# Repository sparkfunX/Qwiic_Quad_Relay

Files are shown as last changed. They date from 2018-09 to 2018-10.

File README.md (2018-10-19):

SparkX Qwiic Quad Relay
========================================

-> SparkX Qwiic Quad Relay (https://cdn.sparkfun.com/assets/parts/1/3/3/6/3/15032-Qwiic_Quad_Relay-01.jpg) <-

[*SparkX Qwiic Quad Relay (SPX-15032)*](https://www.sparkfun.com/products/15032)
The Qwiic Quad Relay is a product designed for switching not one, but **four** high powered devices, from your Arduino or other low powered microcontroller using I<sup>2</sup>C. It's rocking four [relays](https://www.sparkfun.com/products/100) on its' PCB rated up to 5 Amps per channel at 250VAC. Each channel is sporting its own colored LED and silk for easy identification, and has screw terminals for easy connection. 

The board is made to integrate easily into the [Qwiic environment](https://www.sparkfun.com/qwiic) with Qwiic connectors on each side for easy daisy chaining. At the heart of the product is an ATtiny84 with its own I<sup>2</sup>C address awaiting for I<sup>2</sup>C commands that are designated to turn on and off individual channels or _all_ the channels at once! All of this is detailed nicely in provided example code, which also walks you through changing the boards single I<sup>2</sup>C address. There is a four pin header broken out for those of you not taking advantage of the Qwiic connector.

The onboard barrel jack is rated for wall warts in the range, 7-15V but there is a jumper on the underside in the case that your wall wart is 5V. Messing with such high voltage can be dangerous! We've included many safety precautions onto the PCB including, wide traces designed for high amperage, ground isolation between the relay and other circuitry, and a milled out area around the common pin of the relay.

Repository Contents
-------------------

* **/Firmware** - Latest firmware and examples. 
* **/Arduino Example** - Examples on how to use the product with buttons and switches, with hardware interrupts and without.
* **/Hardware** - Eagle design files (.brd, .sch)

License Information
-------------------

This product is _**open source**_! 

Please review the LICENSE.md file for license information. 

If you have any questions or concerns on licensing, please contact techsupport@sparkfun.com.

Please use, reuse, and modify these files as you see fit. Please maintain attribution to SparkFun Electronics and release under the same license.

Distributed as-is; no warranty is given.

- Your friends at SparkFun.

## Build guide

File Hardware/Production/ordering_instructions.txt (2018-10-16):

panel size, 180x118mm
PCB thickness, 1.6mm
number of layers, 2
soldermask color, Black
silkscreen color, White
oz copper, 1oz
finish, HASL lead free
stencils, top+bottom
pcs per panel, 4

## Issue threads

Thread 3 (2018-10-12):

Change resistor values to 1k on LEDs

edspark, 2018-10-12:

edspark, 2018-10-16:
Fixed, see commit:
0d556fc5444e4cb48f6ed6b3425d6cf99cb9de57

Closed 2018-10-16.

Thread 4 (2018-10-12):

Update Relay Package

edspark, 2018-10-12:

edspark, 2018-10-16:
Fixed, see commit:
0d556fc5444e4cb48f6ed6b3425d6cf99cb9de57

Closed 2018-10-16.

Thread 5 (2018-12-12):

Set on/off  not just toggle?

HeneryH, 2018-12-12:
I only see commands in the sample code to toggle individual relays.

I need to set a relay to ON.  Not just toggle it.

What is the command for setting relay x to ON or OFF?

edspark, 2018-12-12:
Hello Henry!

Currently there is only the option to toggle the individual relays. I've been trying to imagine what situation a hard **on** command would be better than going from on->off->on etc. Do you mind sharing why you might need to do that?

As a possible solution to your problem, you could use the command to get the status of the relay before you decide to turn it on or off. For example: "check if relay is on" --> if **off**, toggle relay otherwise leave it **on**.

HeneryH, 2018-12-12:
I have a pi based home controller that communicates with a variety of arduino based wireless nodes.

I just created a node type for the Quad Relay Controller that allows me to set and check any of the relays.

On that controller are buttons to turn any relays on or off.   The functions I am writing take a relay index and a command (on/off).

I suppose that I just need to track its current state and if the requested state isn't the same as the current state then toggle.

Closed 2018-12-12.

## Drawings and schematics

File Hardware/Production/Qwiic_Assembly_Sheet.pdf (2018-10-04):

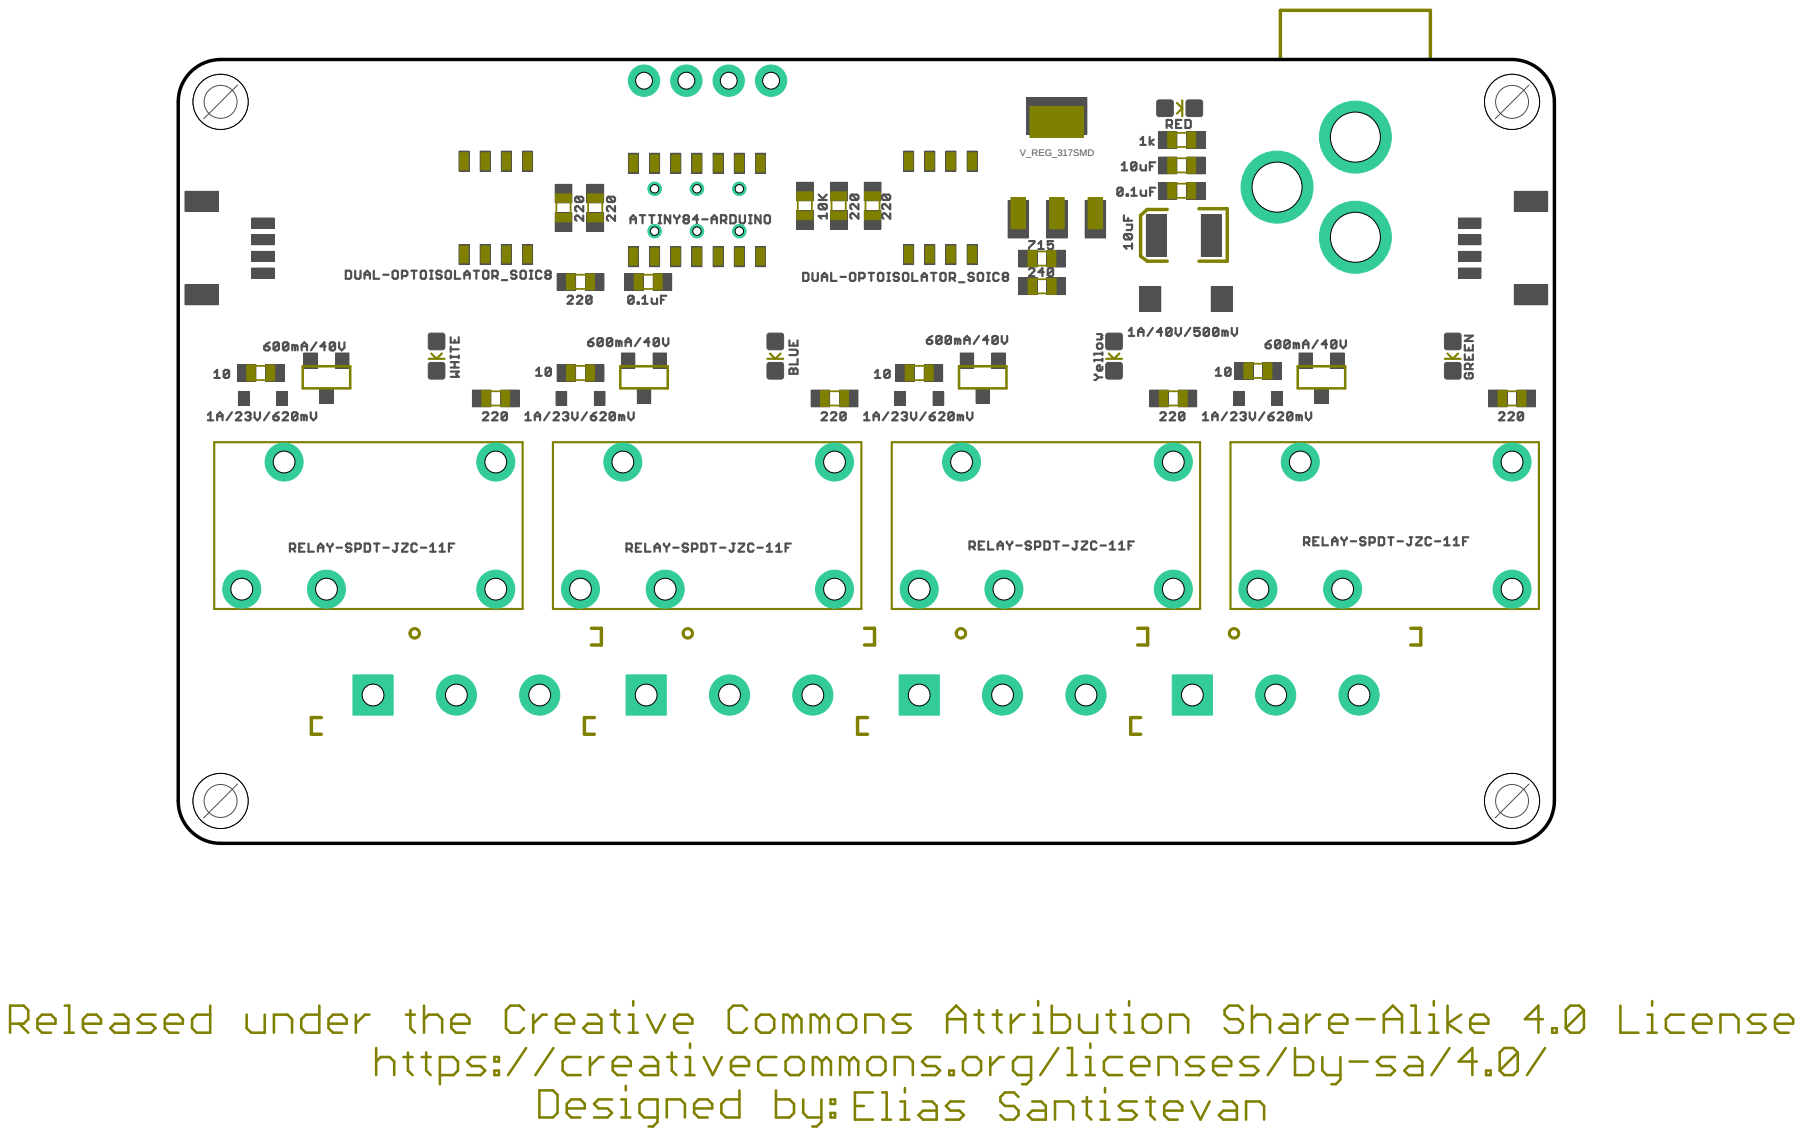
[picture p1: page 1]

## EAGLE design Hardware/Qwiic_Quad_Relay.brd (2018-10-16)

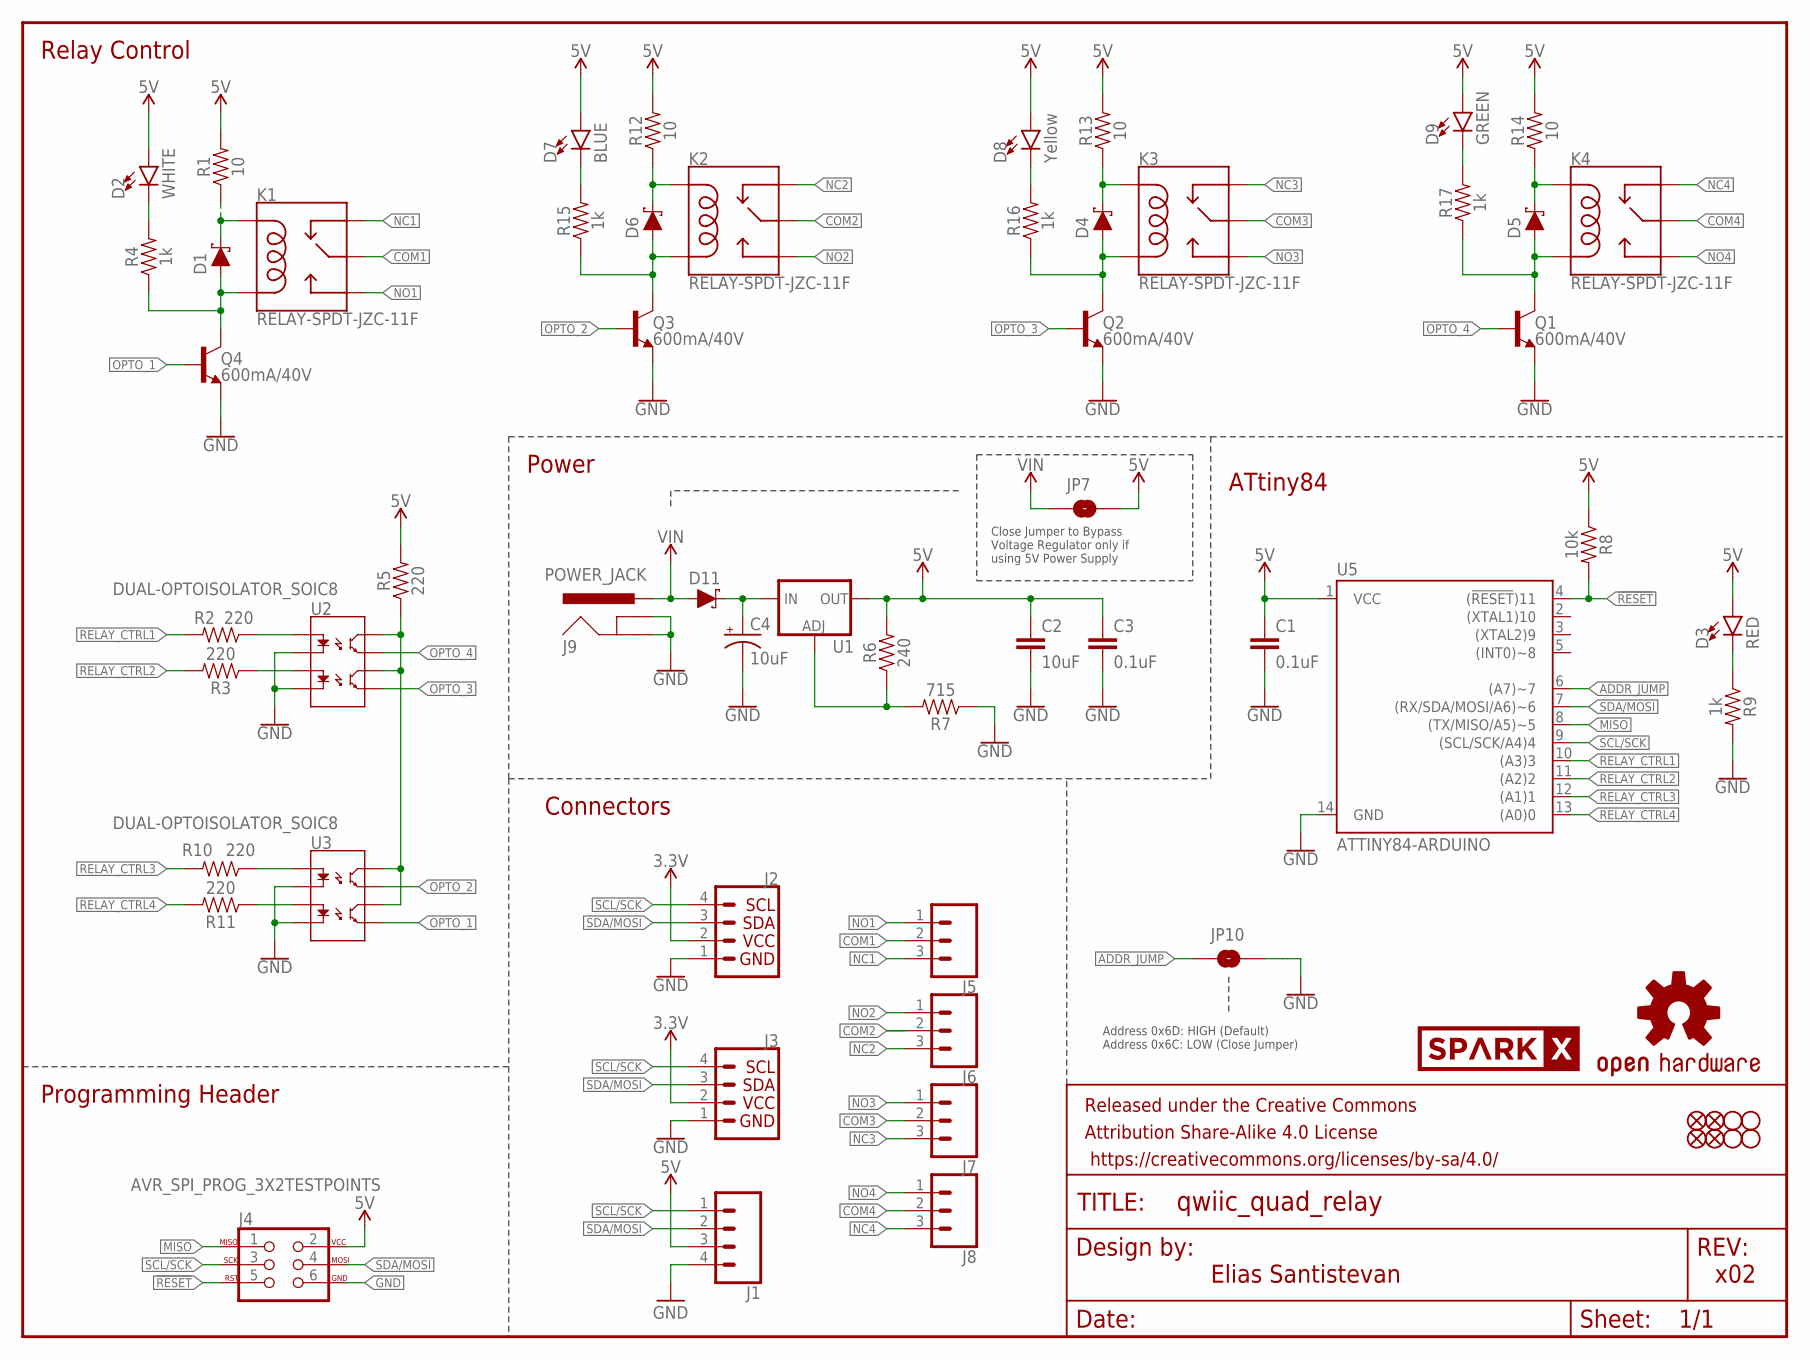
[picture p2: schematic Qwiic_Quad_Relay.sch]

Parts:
C1, C3: 0.1uF; 0603
C2: 10uF; 0603
C4: 10uF; EIA3528
D1, D4, D5, D6: 1A/23V/620mV; SOD-323
D2: WHITE; LED-0603
D3: RED; LED-0603
D7: BLUE; LED-0603
D8: Yellow; LED-0603
D9: GREEN; LED-0603
D11: 1A/40V/500mV; SMA-DIODE
FRAME1: FRAME-LETTER; CREATIVE_COMMONS
J1: CONN_041X04_NO_SILK; 1X04_NO_SILK
J2, J3: Qwiic Right Angle; 1X04_1MM_RA
J4: AVR_SPI_PROG_3X2TESTPOINTS; 2X3_TEST_POINTS
J5, J6, J7, J8: CONN_03-SCREW-5MM; SCREWTERMINAL-5MM-3
J9: POWER_JACK; POWER_JACK_PTH
JP1, JP3, JP4, JP5: STAND-OFF
JP2, JP6, JP8, JP9: FIDUCIAL1X2; FIDUCIAL-1X2
JP7, JP10: JUMPER-SMT_2_NO_SILK; SMT-JUMPER_2_NO_SILK
K1, K2, K3, K4: RELAY-SPDT-JZC-11F; RELAY-JZC
LOGO1: OSHW-LOGOS; OSHW-LOGO-S
Q1, Q2, Q3, Q4: 600mA/40V; SOT23-3
R1, R12, R13, R14: 10; 0603
R2, R3, R5, R10, R11: 220; 0603
R4, R9, R15, R16, R17: 1k; 0603
R6: 240; 0603
R7: 715; 0603
R8: 10k; 0603
U1: V_REG_LM1117SOT223; SOT223
U2, U3: DUAL-OPTOISOLATOR_SOIC8; SO08
U5: ATTINY84-ARDUINO; SO14
U$12: SPARKX-LOGO4; SPARKX-MEDIUM

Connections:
3.3V: J2.2, J3.2
5V: C1.1, C2.1, C3.1, D2.A, D3.A, D7.A, D8.A, D9.A, J1.3, J4.2, JP7.2, R1.2, R5.2, R6.2, R8.1, R12.2, R13.2, R14.2, U1.2 (OUT), U1.4 (OUT), U5.1 (VCC)
!RESET: J4.5, R8.2, U5.4 ((!RESET!)11)
ADDR_JUMP: JP10.1, U5.6 ((A7)~7)
COM1: J5.2, K1.4 (MAIN)
COM2: J6.2, K2.4 (MAIN)
COM3: J7.2, K3.4 (MAIN)
COM4: J8.2, K4.4 (MAIN)
GND: C1.2, C2.2, C3.2, C4.C (-), J1.4, J2.1, J3.1, J4.6, J9.GND, J9.GNDBREAK, JP10.2, Q1.2 (E), Q2.2 (E), Q3.2 (E), Q4.2 (E), R7.1, R9.2, U2.2 (C1), U2.4 (C2), U3.2 (C1), U3.4 (C2), U5.14 (GND)
MISO: J4.1, U5.8 ((TX/MISO/A5)~5)
unnamed: D6.C, K2.5 (COIL1), R12.1
unnamed: D1.A, K1.1 (COIL2), Q4.3 (C), R4.1
unnamed: R11.1, U3.3 (A2)
unnamed: C4.A (+), D11.C, U1.3 (IN)
unnamed: R10.1, U3.1 (A1)
unnamed: R5.1, U2.6 (CL2), U2.8 (CL1), U3.6 (CL2), U3.8 (CL1)
unnamed: D1.C, K1.5 (COIL1), R1.1
unnamed: D2.C, R4.2
unnamed: R2.1, U2.1 (A1)
unnamed: R3.1, U2.3 (A2)
unnamed: D6.A, K2.1 (COIL2), Q3.3 (C), R15.1
unnamed: D3.C, R9.1
unnamed: D4.C, K3.5 (COIL1), R13.1
unnamed: D4.A, K3.1 (COIL2), Q2.3 (C), R16.1
unnamed: D5.C, K4.5 (COIL1), R14.1
unnamed: D5.A, K4.1 (COIL2), Q1.3 (C), R17.1
unnamed: R6.1, R7.2, U1.1 (ADJ)
unnamed: D9.C, R17.2
unnamed: D8.C, R16.2
unnamed: D7.C, R15.2
NC1: J5.3, K1.2 (NC)
NC2: J6.3, K2.2 (NC)
NC3: J7.3, K3.2 (NC)
NC4: J8.3, K4.2 (NC)
NO1: J5.1, K1.3 (NO)
NO2: J6.1, K2.3 (NO)
NO3: J7.1, K3.3 (NO)
NO4: J8.1, K4.3 (NO)
OPTO_1: Q4.1 (B), U3.5 (EM2)
OPTO_2: Q3.1 (B), U3.7 (EM1)
OPTO_3: Q2.1 (B), U2.5 (EM2)
OPTO_4: Q1.1 (B), U2.7 (EM1)
RELAY_CTRL1: R2.2, U5.10 ((A3)3)
RELAY_CTRL2: R3.2, U5.11 ((A2)2)
RELAY_CTRL3: R10.2, U5.12 ((A1)1)
RELAY_CTRL4: R11.2, U5.13 ((A0)0)
SCL/SCK: J1.1, J2.4, J3.4, J4.3, U5.9 ((SCL/SCK/A4)4)
SDA/MOSI: J1.2, J2.3, J3.3, J4.4, U5.7 ((RX/SDA/MOSI/A6)~6)
VIN: D11.A, J9.PWR, JP7.1

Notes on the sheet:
Elias Santistevan
x02
Relay Control
Connectors
ATtiny84
Programming Header
Power
Close Jumper to Bypass Voltage Regulator only if using 5V Power Supply
Address 0x6D: HIGH (Default) Address 0x6C: LOW (Close Jumper)

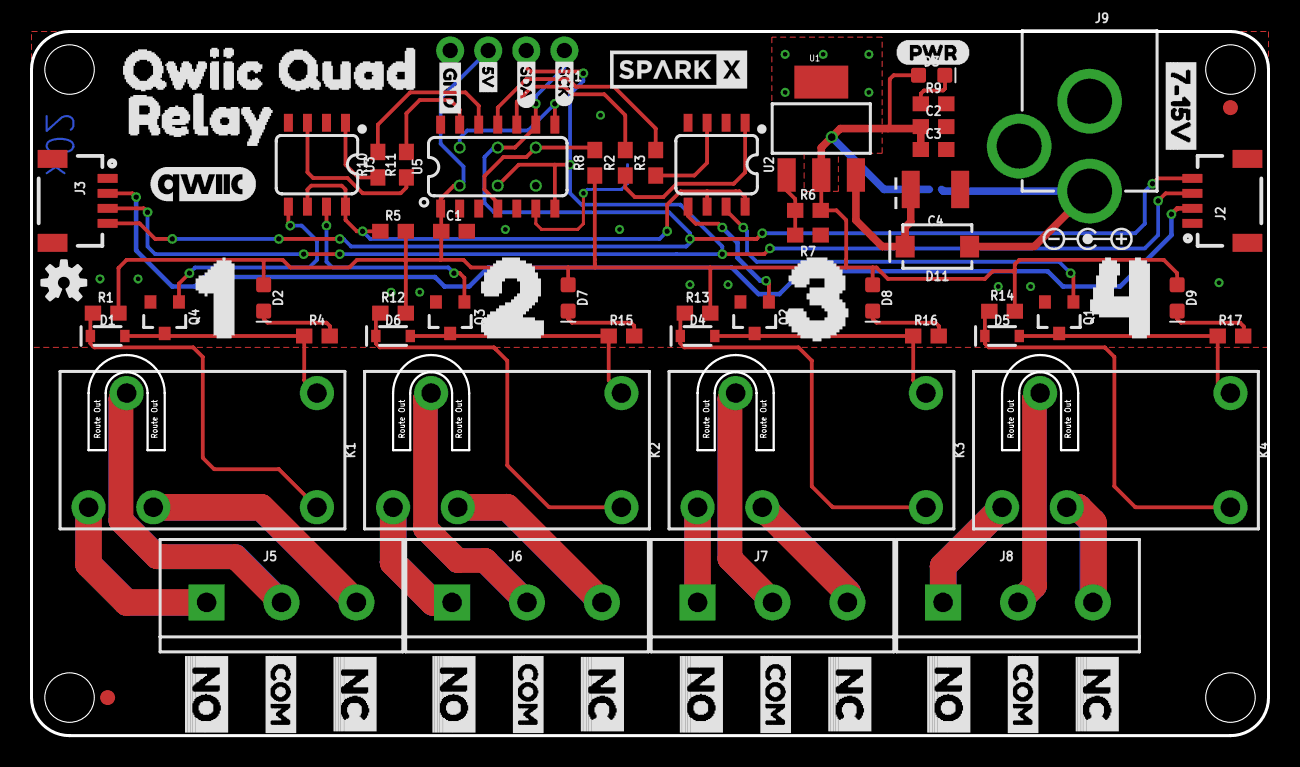
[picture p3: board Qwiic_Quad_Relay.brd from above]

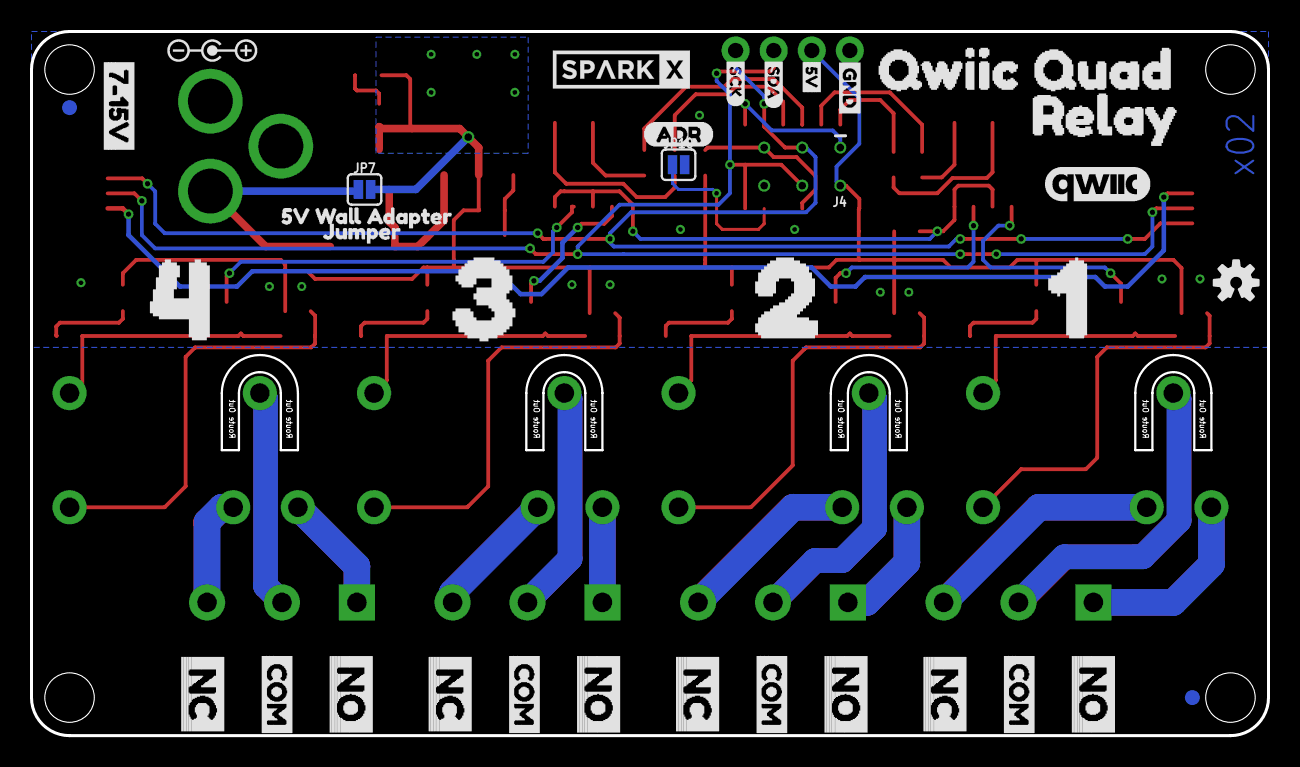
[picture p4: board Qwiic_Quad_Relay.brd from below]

Board: 2 copper layers, 82.5 x 47.0 mm, 121 parts (35 on the bottom side), 49 nets.

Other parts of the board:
U$1: PWR-()-04
U$2, U$40: 20
U$3, U$39: 10
U$4, U$41: 30
U$5, U$42: 40
U$6, U$43: QWIIC_QUAD_0
U$7, U$44: RELAY0
U$8, U$48: SCK-[)-03
U$9, U$45: GND-03
U$10, U$46: 5V0
U$11, U$47: SDA0
U$13: OSHW-LOGO-S
U$14: SPARKX-MEDIUM
U$15, U$18, U$21, U$24, U$27, U$30, U$33, U$36: NO0
U$16, U$19, U$22, U$25, U$28, U$31, U$34, U$37: COM0
U$17, U$20, U$23, U$26, U$29, U$32, U$35, U$38: NC0
U$49, U$53: 7#15V0
U$50: 5V_WALL_ADAPTER0
U$51, U$54: POLARITY_MARKING_CENTER_POSITIVE#JPG
U$52: JUMPER0
U$55, U$57: QWIIC#JPG
U$56: ADR-()-04

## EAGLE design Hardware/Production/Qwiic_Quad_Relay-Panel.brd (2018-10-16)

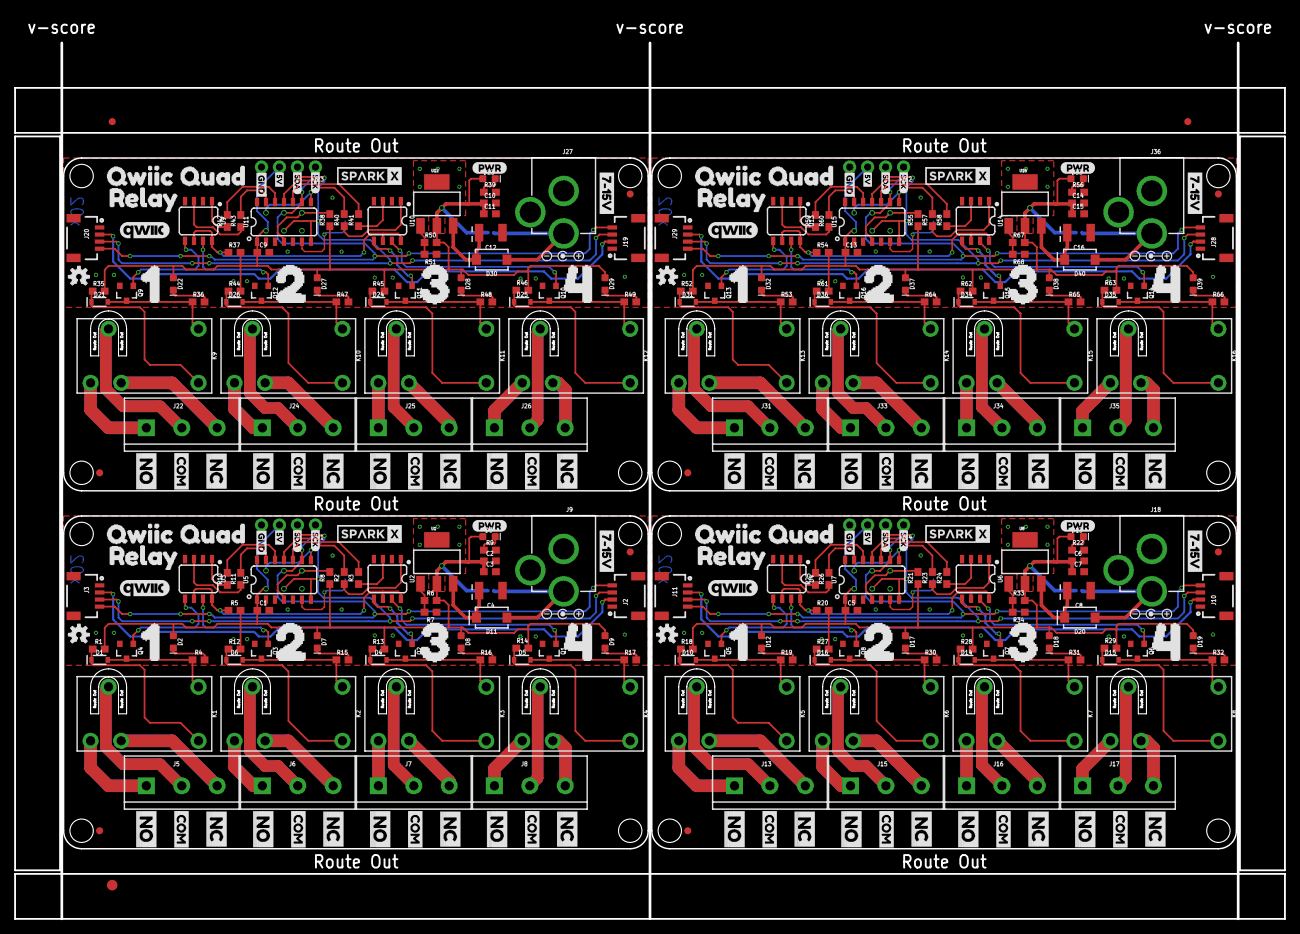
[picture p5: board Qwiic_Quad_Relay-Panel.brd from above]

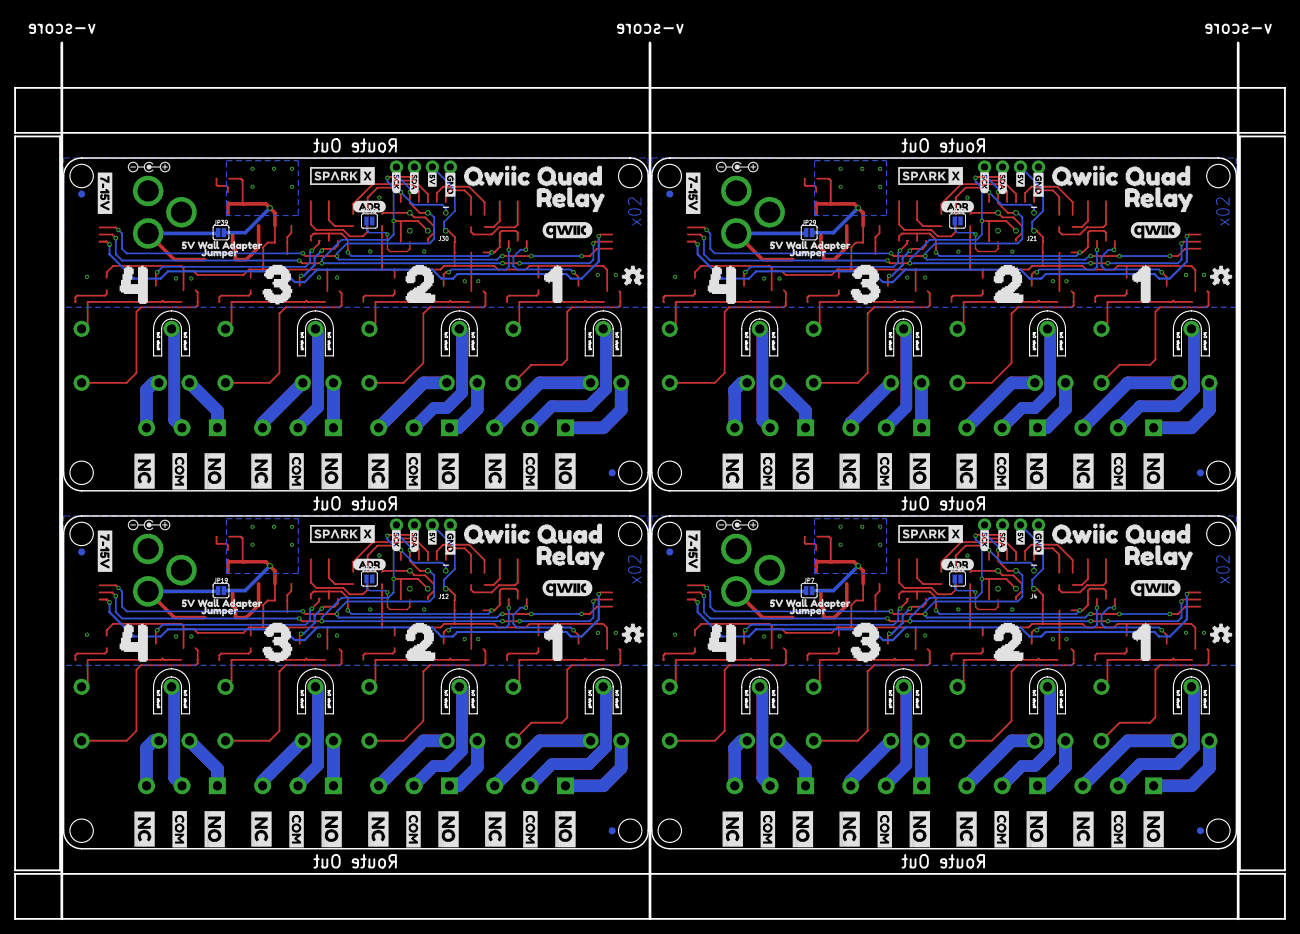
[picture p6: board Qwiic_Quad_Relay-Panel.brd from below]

Board: 2 copper layers, 179.3 x 123.7 mm, 483 parts (140 on the bottom side), 196 nets.

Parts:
C1, C3, C5, C7, C9, C11, C13, C15: 0.1uF; 0603
C2, C6, C10, C14: 10uF; 0603
C4, C8, C12, C16: 10uF; EIA3528
D1, D4, D5, D6, D10, D14, D15, D16, D21, D24, D25, D26, D31, D34, D35, D36: 1A/23V/620mV; SOD-323
D2, D12, D22, D32: WHITE; LED-0603
D3, D13, D23, D33: RED; LED-0603
D7, D17, D27, D37: BLUE; LED-0603
D8, D18, D28, D38: Yellow; LED-0603
D9, D19, D29, D39: GREEN; LED-0603
D11, D20, D30, D40: 1A/40V/500mV; SMA-DIODE
E$1, E$2: FIDUCIAL-1X2
E$3: FIDUCIAL-1.5X3
J1, J14, J23, J32: 1X04_NO_SILK
J2, J3, J10, J11, J19, J20, J28, J29: Qwiic Right Angle; 1X04_1MM_RA
J4, J12, J21, J30: AVR_SPI_PROG_3X2TESTPOINTS; 2X3_TEST_POINTS
J5, J6, J7, J8, J13, J15, J16, J17, J22, J24, J25, J26, J31, J33, J34, J35: SCREWTERMINAL-5MM-3
J9, J18, J27, J36: POWER_JACK; POWER_JACK_PTH
JP1, JP3, JP4, JP5, JP11, JP12, JP15, JP16, JP21, JP22, JP25, JP26, JP31, JP32, JP35, JP36: STAND-OFF
JP2, JP6, JP8, JP9, JP13, JP14, JP17, JP18, JP23, JP24, JP27, JP28, JP33, JP34, JP37, JP38: FIDUCIAL1X2; FIDUCIAL-1X2
JP7, JP10, JP19, JP20, JP29, JP30, JP39, JP40: JUMPER-SMT_2_NO_SILK; SMT-JUMPER_2_NO_SILK
K1, K2, K3, K4, K5, K6, K7, K8, K9, K10, K11, K12, K13, K14, K15, K16: RELAY-SPDT-JZC-11F; RELAY-JZC
LOGO1, LOGO2, LOGO3, LOGO4: OSHW-LOGOS; OSHW-LOGO-S
Q1, Q2, Q3, Q4, Q5, Q6, Q7, Q8, Q9, Q10, Q11, Q12, Q13, Q14, Q15, Q16: 600mA/40V; SOT23-3
R1, R12, R13, R14, R18, R27, R28, R29, R35, R44, R45, R46, R52, R61, R62, R63: 10; 0603
R2, R3, R5, R10, R11, R20, R23, R24, R25, R26, R37, R40, R41, R42, R43, R54, R57, R58, R59, R60: 220; 0603
R4, R9, R15, R16, R17, R19, R22, R30, R31, R32, R36, R39, R47, R48, R49, R53, R56, R64, R65, R66: 1k; 0603
R6, R33, R50, R67: 240; 0603
R7, R34, R51, R68: 715; 0603
R8, R21, R38, R55: 10k; 0603
U1, U8, U12, U16: SOT223
U2, U3, U4, U6, U9, U10, U13, U14: DUAL-OPTOISOLATOR_SOIC8; SO08
U5, U7, U11, U15: ATTINY84-ARDUINO; SO14
U$1, U$58, U$115, U$172: PWR-()-04
U$2, U$40, U$59, U$92, U$116, U$149, U$173, U$206: 20
U$3, U$39, U$60, U$91, U$117, U$148, U$174, U$205: 10
U$4, U$41, U$61, U$93, U$118, U$150, U$175, U$207: 30
U$5, U$42, U$62, U$94, U$119, U$151, U$176, U$208: 40
U$6, U$43, U$63, U$95, U$120, U$152, U$177, U$209: QWIIC_QUAD_0
U$7, U$44, U$64, U$96, U$121, U$153, U$178, U$210: RELAY0
U$8, U$48, U$99, U$106, U$156, U$163, U$213, U$220: SCK-[)-03
U$9, U$45, U$100, U$103, U$157, U$160, U$214, U$217: GND-03
U$10, U$46, U$101, U$104, U$158, U$161, U$215, U$218: 5V0
U$11, U$47, U$102, U$105, U$159, U$162, U$216, U$219: SDA0
U$12, U$65, U$122, U$179: SPARKX-LOGO4; SPARKX-MEDIUM
U$13, U$97, U$154, U$211: OSHW-LOGO-S
U$14, U$66, U$123, U$180: SPARKX-MEDIUM
U$15, U$18, U$21, U$24, U$27, U$30, U$33, U$36, U$67, U$70, U$73, U$76, U$79, U$82, U$85, U$88, U$124, U$127, U$130, U$133, U$136, U$139, U$142, U$145, U$181, U$184, U$187, U$190, U$193, U$196, U$199, U$202: NO0
U$16, U$19, U$22, U$25, U$28, U$31, U$34, U$37, U$68, U$71, U$74, U$77, U$80, U$83, U$86, U$89, U$125, U$128, U$131, U$134, U$137, U$140, U$143, U$146, U$182, U$185, U$188, U$191, U$194, U$197, U$200, U$203: COM0
U$17, U$20, U$23, U$26, U$29, U$32, U$35, U$38, U$69, U$72, U$75, U$78, U$81, U$84, U$87, U$90, U$126, U$129, U$132, U$135, U$138, U$141, U$144, U$147, U$183, U$186, U$189, U$192, U$195, U$198, U$201, U$204: NC0
U$49, U$53, U$98, U$108, U$155, U$165, U$212, U$222: 7#15V0
U$50, U$112, U$169, U$226: 5V_WALL_ADAPTER0
U$51, U$54, U$107, U$109, U$164, U$166, U$221, U$223: POLARITY_MARKING_CENTER_POSITIVE#JPG
U$52, U$113, U$170, U$227: JUMPER0
U$55, U$57, U$110, U$111, U$167, U$168, U$224, U$225: QWIIC#JPG
U$56, U$114, U$171, U$228: ADR-()-04

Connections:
3.3V: J2.2, J3.2
3.3V1: J10.2, J11.2
3.3V2: J19.2, J20.2
3.3V3: J28.2, J29.2
5V: C1.1, C2.1, C3.1, D2.A, D3.A, D7.A, D8.A, D9.A, J1.3, J4.2, JP7.2, R1.2, R5.2, R6.2, R8.1, R12.2, R13.2, R14.2, U1.2, U1.4, U5.1
5V1: C5.1, C6.1, C7.1, D12.A, D13.A, D17.A, D18.A, D19.A, J12.2, J14.3, JP19.2, R18.2, R20.2, R21.1, R27.2, R28.2, R29.2, R33.2, U7.1, U8.2, U8.4
5V2: C9.1, C10.1, C11.1, D22.A, D23.A, D27.A, D28.A, D29.A, J21.2, J23.3, JP29.2, R35.2, R37.2, R38.1, R44.2, R45.2, R46.2, R50.2, U11.1, U12.2, U12.4
5V3: C13.1, C14.1, C15.1, D32.A, D33.A, D37.A, D38.A, D39.A, J30.2, J32.3, JP39.2, R52.2, R54.2, R55.1, R61.2, R62.2, R63.2, R67.2, U15.1, U16.2, U16.4
!RESET: J4.5, R8.2, U5.4
!RESET1: J12.5, R21.2, U7.4
!RESET2: J21.5, R38.2, U11.4
!RESET3: J30.5, R55.2, U15.4
ADDR_JUMP: JP10.1, U5.6
ADDR_JUMP1: JP20.1, U7.6
ADDR_JUMP2: JP30.1, U11.6
ADDR_JUMP3: JP40.1, U15.6
COM1: J5.2, K1.4
COM2: J6.2, K2.4
COM3: J7.2, K3.4
COM4: J8.2, K4.4
COM5: J13.2, K5.4
COM6: J15.2, K6.4
COM7: J16.2, K7.4
COM8: J17.2, K8.4
COM9: J22.2, K9.4
COM10: J24.2, K10.4
COM11: J25.2, K11.4
COM12: J26.2, K12.4
COM13: J31.2, K13.4
COM14: J33.2, K14.4
COM15: J34.2, K15.4
COM16: J35.2, K16.4
GND: C1.2, C2.2, C3.2, C4.C, J1.4, J2.1, J3.1, J4.6, J9.GND, J9.GNDBREAK, JP10.2, Q1.2, Q2.2, Q3.2, Q4.2, R7.1, R9.2, U2.2, U2.4, U3.2, U3.4, U5.14
GND1: C5.2, C6.2, C7.2, C8.C, J10.1, J11.1, J12.6, J14.4, J18.GND, J18.GNDBREAK, JP20.2, Q5.2, Q6.2, Q7.2, Q8.2, R22.2, R34.1, U4.2, U4.4, U6.2, U6.4, U7.14
GND2: C9.2, C10.2, C11.2, C12.C, J19.1, J20.1, J21.6, J23.4, J27.GND, J27.GNDBREAK, JP30.2, Q9.2, Q10.2, Q11.2, Q12.2, R39.2, R51.1, U9.2, U9.4, U10.2, U10.4, U11.14
GND3: C13.2, C14.2, C15.2, C16.C, J28.1, J29.1, J30.6, J32.4, J36.GND, J36.GNDBREAK, JP40.2, Q13.2, Q14.2, Q15.2, Q16.2, R56.2, R68.1, U13.2, U13.4, U14.2, U14.4, U15.14
MISO: J4.1, U5.8
MISO1: J12.1, U7.8
MISO2: J21.1, U11.8
MISO3: J30.1, U15.8
unnamed: D6.C, K2.5, R12.1
unnamed: D1.A, K1.1, Q4.3, R4.1
unnamed: R11.1, U3.3
unnamed: C4.A, D11.C, U1.3
unnamed: R10.1, U3.1
unnamed: R5.1, U2.6, U2.8, U3.6, U3.8
unnamed: D1.C, K1.5, R1.1
unnamed: D2.C, R4.2
unnamed: R2.1, U2.1
unnamed: D10.A, K5.1, Q5.3, R19.1
unnamed: R3.1, U2.3
unnamed: D6.A, K2.1, Q3.3, R15.1
unnamed: D3.C, R9.1
unnamed: D4.C, K3.5, R13.1
unnamed: D4.A, K3.1, Q2.3, R16.1
unnamed: D5.C, K4.5, R14.1
unnamed: D5.A, K4.1, Q1.3, R17.1
unnamed: D10.C, K5.5, R18.1
unnamed: R6.1, R7.2, U1.1
unnamed: D9.C, R17.2
unnamed: D8.C, R16.2
unnamed: D7.C, R15.2
unnamed: D12.C, R19.2
unnamed: D13.C, R22.1
unnamed: R26.1, U4.3
unnamed: R25.1, U4.1
unnamed: R20.1, U4.6, U4.8, U6.6, U6.8
unnamed: R23.1, U6.1
unnamed: R24.1, U6.3
unnamed: D16.C, K6.5, R27.1
unnamed: D16.A, K6.1, Q8.3, R30.1
unnamed: D14.C, K7.5, R28.1
unnamed: D14.A, K7.1, Q7.3, R31.1
unnamed: D15.C, K8.5, R29.1
unnamed: D15.A, K8.1, Q6.3, R32.1
unnamed: D19.C, R32.2
unnamed: D18.C, R31.2
unnamed: D17.C, R30.2
unnamed: R33.1, R34.2, U8.1
unnamed: C8.A, D20.C, U8.3
unnamed: D21.A, K9.1, Q9.3, R36.1
unnamed: D21.C, K9.5, R35.1
unnamed: D22.C, R36.2
unnamed: D23.C, R39.1
unnamed: R43.1, U9.3
unnamed: R42.1, U9.1
unnamed: R37.1, U9.6, U9.8, U10.6, U10.8
unnamed: R40.1, U10.1
unnamed: R41.1, U10.3
unnamed: D26.C, K10.5, R44.1
unnamed: D26.A, K10.1, Q12.3, R47.1
unnamed: D24.C, K11.5, R45.1
unnamed: D24.A, K11.1, Q11.3, R48.1
unnamed: D25.C, K12.5, R46.1
unnamed: D25.A, K12.1, Q10.3, R49.1
unnamed: D29.C, R49.2
unnamed: D28.C, R48.2
unnamed: D27.C, R47.2
unnamed: R50.1, R51.2, U12.1
unnamed: C12.A, D30.C, U12.3
unnamed: D31.A, K13.1, Q13.3, R53.1
unnamed: D31.C, K13.5, R52.1
unnamed: D32.C, R53.2
unnamed: D33.C, R56.1
unnamed: R60.1, U13.3
unnamed: R59.1, U13.1
unnamed: R54.1, U13.6, U13.8, U14.6, U14.8
unnamed: R57.1, U14.1
unnamed: R58.1, U14.3
unnamed: D36.C, K14.5, R61.1
unnamed: D36.A, K14.1, Q16.3, R64.1
unnamed: D34.C, K15.5, R62.1
unnamed: D34.A, K15.1, Q15.3, R65.1
unnamed: D35.C, K16.5, R63.1
unnamed: D35.A, K16.1, Q14.3, R66.1
unnamed: D39.C, R66.2
unnamed: D38.C, R65.2
unnamed: D37.C, R64.2
unnamed: R67.1, R68.2, U16.1
unnamed: C16.A, D40.C, U16.3
NC1: J5.3, K1.2
NC2: J6.3, K2.2
NC3: J7.3, K3.2
NC4: J8.3, K4.2
NC5: J13.3, K5.2
NC6: J15.3, K6.2
NC7: J16.3, K7.2
NC8: J17.3, K8.2
NC9: J22.3, K9.2
NC10: J24.3, K10.2
NC11: J25.3, K11.2
NC12: J26.3, K12.2
NC13: J31.3, K13.2
NC14: J33.3, K14.2
NC15: J34.3, K15.2
NC16: J35.3, K16.2
NO1: J5.1, K1.3
NO2: J6.1, K2.3
NO3: J7.1, K3.3
NO4: J8.1, K4.3
NO5: J13.1, K5.3
NO6: J15.1, K6.3
NO7: J16.1, K7.3
NO8: J17.1, K8.3
NO9: J22.1, K9.3
NO10: J24.1, K10.3
NO11: J25.1, K11.3
NO12: J26.1, K12.3
NO13: J31.1, K13.3
NO14: J33.1, K14.3
NO15: J34.1, K15.3
NO16: J35.1, K16.3
OPTO_1: Q4.1, U3.5
OPTO_2: Q3.1, U3.7
OPTO_3: Q2.1, U2.5
OPTO_4: Q1.1, U2.7
OPTO_5: Q5.1, U4.5
OPTO_6: Q8.1, U4.7
OPTO_7: Q7.1, U6.5
OPTO_8: Q6.1, U6.7
OPTO_9: Q9.1, U9.5
OPTO_10: Q12.1, U9.7
OPTO_11: Q11.1, U10.5
OPTO_12: Q10.1, U10.7
OPTO_13: Q13.1, U13.5
OPTO_14: Q16.1, U13.7
OPTO_15: Q15.1, U14.5
OPTO_16: Q14.1, U14.7
RELAY_CTRL1: R2.2, U5.10
RELAY_CTRL2: R3.2, U5.11
RELAY_CTRL3: R10.2, U5.12
RELAY_CTRL4: R11.2, U5.13
RELAY_CTRL5: R23.2, U7.10
RELAY_CTRL6: R24.2, U7.11
RELAY_CTRL7: R25.2, U7.12
RELAY_CTRL8: R26.2, U7.13
RELAY_CTRL9: R40.2, U11.10
RELAY_CTRL10: R41.2, U11.11
RELAY_CTRL11: R42.2, U11.12
RELAY_CTRL12: R43.2, U11.13
RELAY_CTRL13: R57.2, U15.10
RELAY_CTRL14: R58.2, U15.11
RELAY_CTRL15: R59.2, U15.12
RELAY_CTRL16: R60.2, U15.13
SCL/SCK: J1.1, J2.4, J3.4, J4.3, U5.9
SCL/SCK1: J10.4, J11.4, J12.3, J14.1, U7.9
SCL/SCK2: J19.4, J20.4, J21.3, J23.1, U11.9
SCL/SCK3: J28.4, J29.4, J30.3, J32.1, U15.9
SDA/MOSI: J1.2, J2.3, J3.3, J4.4, U5.7
SDA/MOSI1: J10.3, J11.3, J12.4, J14.2, U7.7
SDA/MOSI2: J19.3, J20.3, J21.4, J23.2, U11.7
SDA/MOSI3: J28.3, J29.3, J30.4, J32.2, U15.7
VIN: D11.A, J9.PWR, JP7.1
VIN1: D20.A, J18.PWR, JP19.1
VIN2: D30.A, J27.PWR, JP29.1
VIN3: D40.A, J36.PWR, JP39.1

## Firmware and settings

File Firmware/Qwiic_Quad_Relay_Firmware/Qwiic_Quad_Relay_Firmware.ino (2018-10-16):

/*
  An I2C based KeyPad
  By: Elias Santistevan
  SparkFun Electronics
  Date: October 2018
  License: This code is public domain but you buy me a beer if you use this and we meet someday (Beerware license).

  Feel like supporting our work? Buy a board from SparkFun!
	<Product Page Here>

  To install support for ATtiny84 in Arduino IDE: https://github.com/SpenceKonde/ATTinyCore/blob/master/Installation.md
  This core is installed from the Board Manager menu
  This core has built in support for I2C S/M and serial
  If you have Dave Mellis' ATtiny installed you may need to remove it from \Users\xx\AppData\Local\Arduino15\Packages

  To support 400kHz I2C communication reliably ATtiny84 needs to run at 8MHz. This requires user to
  click on 'Burn Bootloader' before code is loaded.
*/

#include <Wire.h>

#include <EEPROM.h>

#define LOCATION_I2C_ADDRESS 0x01 //Location in EEPROM where the I2C address is stored
#define I2C_ADDRESS_DEFAULT 109 //0x6D Default address
#define I2C_ADDRESS_JUMPER 108 //0x6C Address if address jumper is closed

#define COMMAND_CHANGE_ADDRESS 0xC7

// Commands that toggle the relays.
#define RELAY_ONE_TOGGLE 0x01
#define RELAY_TWO_TOGGLE 0x02
#define RELAY_THREE_TOGGLE 0x03
#define RELAY_FOUR_TOGGLE 0x04
#define TURN_ALL_OFF 0xA 
#define TURN_ALL_ON 0xB 
#define TOGGLE_ALL 0xC

// Commands to request the state of the relay, whether it is currently on or
// off. 
#define RELAY_STATUS_ONE  0x05 
#define RELAY_STATUS_TWO  0x06
#define RELAY_STATUS_THREE 0x07
#define RELAY_STATUS_FOUR 0x08

// Messages for requests that state whether a relay is on or off. 
#define RELAY_IS_ON 0xF
#define RELAY_IS_OFF 0x0

volatile uint8_t setting_i2c_address = I2C_ADDRESS_DEFAULT; 
volatile uint8_t COMMAND;  //Variable for incoming I2C commands. 

const uint8_t addrPin = 7; 
const uint8_t resetPin = 11; 

// The four relay pins on the ATtiny84A.
const uint8_t relayCtrl1 = 0; 
const uint8_t relayCtrl2 = 1; 
const uint8_t relayCtrl3 = 2; 
const uint8_t relayCtrl4 = 3; 

// This 'status' array keeps track of the state of the relays. 
uint8_t status[] = {RELAY_IS_OFF, RELAY_IS_OFF, RELAY_IS_OFF, RELAY_IS_OFF};

void setup(void)
{
  pinMode(addrPin, INPUT_PULLUP); //Default HIGH = 0x6D or 109
  pinMode(resetPin, INPUT_PULLUP);

  pinMode(relayCtrl1, OUTPUT); //Relay pins to OUTPUT
  pinMode(relayCtrl2, OUTPUT);
  pinMode(relayCtrl3, OUTPUT);
  pinMode(relayCtrl4, OUTPUT);

  readSystemSettings(); //Load all system settings from EEPROM
  startI2C(); //Determine the I2C address we should be using and begin listening on I2C bus
}

void loop(void) {
}

void receiveEvent(int numberOfBytesReceived)
{
  while( Wire.available() ) {
    //Record uint8_ts to local array
    COMMAND = Wire.read();

    if(COMMAND == COMMAND_CHANGE_ADDRESS){ //Set new I2C address 
      if(Wire.available()) {
        setting_i2c_address = Wire.read();

        //Error check
        if(setting_i2c_address < 0x08 || setting_i2c_address > 0x77)
          continue; //Command failed. This address is out of bounds.

        EEPROM.write(LOCATION_I2C_ADDRESS, setting_i2c_address);

        //Our I2C address may have changed because of user's command
        startI2C(); //Determine the I2C address we should be using and begin listening on I2C bus
      }
    }

    // Relay control for relay 1, check the state, toggle the relay, change the
    // state.
    else if(COMMAND == RELAY_ONE_TOGGLE){
      if(status[0] == RELAY_IS_OFF){
        digitalWrite(relayCtrl1, HIGH); 
        status[0] = RELAY_IS_ON; 
      }
      else if(status[0] == RELAY_IS_ON ){
        digitalWrite(relayCtrl1, LOW); 
        status[0] = RELAY_IS_OFF; 
      }
    }

    // Relay control for relay 2, check the state, toggle the relay, change the
    // state.
    else if(COMMAND == RELAY_TWO_TOGGLE){
      if(status[1] == RELAY_IS_OFF){
        digitalWrite(relayCtrl2, HIGH); 
        status[1] = RELAY_IS_ON; 
      }
      else if(status[1] == RELAY_IS_ON ){
        digitalWrite(relayCtrl2, LOW); 
        status[1] = RELAY_IS_OFF; 
      }
    }

    // Relay control for relay 3, check the state, toggle the relay, change the
    // state.
    else if(COMMAND == RELAY_THREE_TOGGLE){
      if(status[2] == RELAY_IS_OFF){
        digitalWrite(relayCtrl3, HIGH); 
        status[2] = RELAY_IS_ON; 
      }
      else if(status[2] == RELAY_IS_ON ){
        digitalWrite(relayCtrl3, LOW); 
        status[2] = RELAY_IS_OFF; 
      }
    }

    // Relay control for relay 4, check the state, toggle the relay, change the
    // state.
    else if(COMMAND == RELAY_FOUR_TOGGLE){
      if(status[3] == RELAY_IS_OFF){
        digitalWrite(relayCtrl4, HIGH); 
        status[3] = RELAY_IS_ON; 
      }
      else if(status[3] == RELAY_IS_ON ){
        digitalWrite(relayCtrl4, LOW); 
        status[3] = RELAY_IS_OFF; 
      }
    }

    // Turn all relays off, record all of their states. 
    else if(COMMAND == TURN_ALL_OFF){
      digitalWrite(relayCtrl1, LOW); 
      digitalWrite(relayCtrl2, LOW); 
      digitalWrite(relayCtrl3, LOW); 
      digitalWrite(relayCtrl4, LOW); 
      for(int i = 0; i < sizeof(status); i++){
        status[i] = RELAY_IS_OFF;
      }
    }

    // Turn it up to ELEVEN, all on! Record their states to the status array.
    else if(COMMAND == TURN_ALL_ON){
      digitalWrite(relayCtrl1, HIGH); 
      digitalWrite(relayCtrl2, HIGH); 
      digitalWrite(relayCtrl3, HIGH); 
      digitalWrite(relayCtrl4, HIGH); 
      for(int i = 0; i < sizeof(status); i++){
        status[i] = RELAY_IS_ON;
      }
    }

    // This command will put each relay into it's opposite state: relays that
    // are on will be turned off and vice versa. 
    else if(COMMAND == TOGGLE_ALL){
      for(int i = 0; i < sizeof(status); i++){
        if(status[i] == RELAY_IS_ON){
          // Remember that the relays are on pins 0-4, which aligns with the
          // status array. With that, I'll be using the iterator 'i' to write
          // the pins HIGH and LOW. 
          digitalWrite(i, LOW); 
          status[i] = RELAY_IS_OFF;
          continue; 
        }
        //Would be an else statement, but for clarity....
        else if(status[i] == RELAY_IS_OFF){
          digitalWrite(i, HIGH);
          status[i] = RELAY_IS_ON;
        }
      }
    }

  }
}

void requestEvent()
{
  // In the you want to request multiple relay states without having to do
  // multiple "requestFrom"'s in code, the request COMMAND will iterate through
  // the sequential response commands (0x05 -> 0x08). For example, if you
  // request 2 bytes, starting with relay three (0x07), then you'll receive the
  // state of relay three and relay four(0x08). If you request the state of
  // three relays, starting with four, you'll get four(0x08), one(0x05),
  // two(0x06) etc.
  if(COMMAND == RELAY_STATUS_ONE){
      Wire.write(status[0]);
      COMMAND++; 
  }
  if(COMMAND == RELAY_STATUS_TWO){
      Wire.write(status[1]);
      COMMAND++;
  }
  if(COMMAND == RELAY_STATUS_THREE){
      Wire.write(status[2]);
      COMMAND++; 
  } 
  if(COMMAND == RELAY_STATUS_FOUR){
      Wire.write(status[3]);
      COMMAND = 0x05; 
  }
}

void readSystemSettings(void)
{
  //Read what I2C address we should use
  setting_i2c_address = EEPROM.read(LOCATION_I2C_ADDRESS);
  if(setting_i2c_address == 255) {
    setting_i2c_address = I2C_ADDRESS_DEFAULT; //By default, we listen for I2C_ADDRESS_DEFAULT
    EEPROM.write(LOCATION_I2C_ADDRESS, setting_i2c_address);
  }
}

//Begin listening on I2C bus as I2C slave using the global variable setting_i2c_address
void startI2C()
{
  Wire.end(); //Before we can change addresses we need to stop
  
  if(digitalRead(addrPin) == HIGH) //Default HIGH
    Wire.begin(setting_i2c_address); //Start I2C and answer calls using address from EEPROM
  else
    Wire.begin(I2C_ADDRESS_JUMPER);//Closed jumper is LOW

  //The connections to the interrupts are severed when a Wire.begin occurs. So re-declare them.
  Wire.onReceive(receiveEvent);
  Wire.onRequest(requestEvent);
}

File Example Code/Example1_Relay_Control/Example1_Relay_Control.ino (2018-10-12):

/*
  This Qwiic Quad relay is a product with four channels for switching high AC voltge.
  By: Elias Santistevan
  SparkFun Electronics
  Date: October 2018

  License: This code is public domain but you buy me a beer if you use 
	this and we meet someday (Beerware license).

	This example attaches four buttons to four digital I/O pins and each controls
  a different relay.  When a button is pressed it sends and I2C command indicating 
  which channel on the relay board to turn on. This example also includes a
  function to check whether the relays are on or off.  

*/

#include <Wire.h>

#define RELAY_ADDR 0x6D //Only address that exists for this product

// Here are the commands to turn on and off individual relays. 
#define TOGGLE_RELAY_ONE 0x01
#define TOGGLE_RELAY_TWO 0x02
#define TOGGLE_RELAY_THREE 0x03
#define TOGGLE_RELAY_FOUR 0x04

// Here are the commands to turn them all off or on. 
#define TURN_ALL_ON  0xB 
#define TURN_ALL_OFF 0xA

//Here is the command to toggle every relay.
#define TOGGLE_ALL 0xC 

// Here are the commands to check on the 'status' of the relay i.e. whether the
// relay is on or off.
#define RELAY_ONE_STATUS 0x05
#define RELAY_TWO_STATUS 0x06
#define RELAY_THREE_STATUS 0x07
#define RELAY_FOUR_STATUS 0x08

//Four buttons
const uint8_t yellow_btn = 2;
const uint8_t blue_btn = 3;
const uint8_t red_btn =  4;
const uint8_t green_btn =  5;

void setup()
{
  Wire.begin(); 
  Serial.begin(115200);
	
	//Use internal resitors to keep them in a known high state. 
  pinMode(yellow_btn, INPUT_PULLUP);
  pinMode(blue_btn, INPUT_PULLUP);
  pinMode(red_btn, INPUT_PULLUP);
  pinMode(green_btn, INPUT_PULLUP);

  get_relays_status();
}

void loop()
{
	// Since we'll only ever want the relay to be on or off,
	// the logic is handled by the product. Here we're just pressing buttons and
  // putting a small 400 ms debounce. 

	//button one, relay one!
  if(digitalRead(yellow_btn) == LOW){
    Serial.println("Yellow Button");
    Wire.beginTransmission(RELAY_ADDR);
    Wire.write(TOGGLE_RELAY_ONE);
    Wire.endTransmission();
		delay(400);
  }

	//button two, relay two!
  if(digitalRead(blue_btn) == LOW){
    Serial.println("Blue Button");
    Wire.beginTransmission(RELAY_ADDR);
    Wire.write(TOGGLE_RELAY_TWO);
    Wire.endTransmission();
		delay(400);
  }

	//button three, toggle every relay: on -> off and off -> on.
  if(digitalRead(red_btn) == LOW){
    Serial.println("Red Button");
    Wire.beginTransmission(RELAY_ADDR);
    Wire.write(TOGGLE_ALL);
    Wire.endTransmission();
		delay(400);
  }

	//button four, turn off all the relays!
  if(digitalRead(green_btn) == LOW){
    Serial.println("Green Button");
    Wire.beginTransmission(RELAY_ADDR);
    Wire.write(TURN_ALL_OFF);
    Wire.endTransmission();
		delay(400);
  }
}

void get_relays_status(){
  int i = 1; 
  Wire.beginTransmission(RELAY_ADDR);
  // Change the Wire.write statment below to the desired relay you want to check on.
  Wire.write(RELAY_ONE_STATUS); 
  Wire.endTransmission();
  //  We want the states of all the relays so we're requesting four bytes, i.e.
  //  four relays. If you request 2 bytes, it will give you the state of two relays! 
  Wire.requestFrom(RELAY_ADDR, 4); 

  // Print it out, 0 == OFF and 15 == ON.  
  while(Wire.available()){
    Serial.print("Relay "); 
    Serial.print(i); 
    Serial.print(": "); 
    Serial.println(Wire.read());
    i++;
  }

}

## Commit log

2018-09-18 Ready for review
    [Qwiic_Quad_Relay.brd, Qwiic_Quad_Relay.sch]
2018-09-21 Silk, diode, different LEDs, jumper, rounded route out
    I changed to better consistency of label size, a center positive label for the barrel jack, and added the new qwiic label to our new standard. Used different color LEDs so that a person could identif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
    [Qwiic_Quad_Relay.brd, Qwiic_Quad_Relay.sch]
2018-09-21 Changed internal route out to milling, also production files.
    [Qwiic_Quad_Relay-Panel.GBL, Qwiic_Quad_Relay-Panel.GBO, Qwiic_Quad_Relay-Panel.GBS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]
2018-10-04 Example Code, Firmware, Changes to board
    Example Code is not done, firmware as well, unless I want to add a bit more to toggle all channels to opposite states. Production Files have been added. Induction resistor has been changed to a 100 O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
    [Qwiic_Quad_Relay-Panel.GBL, Qwiic_Quad_Relay-Panel.GBO, Qwiic_Quad_Relay-Panel.GBS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]
2018-10-12 Updates to board file, example code, and firmware for release!
    [Qwiic_Quad_Relay.brd, Qwiic_Quad_Relay.sch]
2018-10-16 Version x02
    Changes:
    Added thermal polygon around and underneath the voltage regulator.
    Changed LED resistor values to 1k because they were too bright.
    Added address jumper.
    Modified relay pins
    Changed Firmware to add second I2C address
    [Qwiic_Quad_Relay.brd, Qwiic_Quad_Relay.sch]
2018-10-16 Production Files Updated
    [Qwiic_Quad_Relay-Panel.GBL, Qwiic_Quad_Relay-Panel.GBO, Qwiic_Quad_Relay-Panel.GBS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]

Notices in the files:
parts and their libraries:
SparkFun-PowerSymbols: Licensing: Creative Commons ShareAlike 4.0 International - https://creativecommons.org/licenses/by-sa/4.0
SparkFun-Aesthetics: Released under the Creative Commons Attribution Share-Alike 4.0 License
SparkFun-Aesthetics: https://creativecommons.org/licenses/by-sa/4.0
